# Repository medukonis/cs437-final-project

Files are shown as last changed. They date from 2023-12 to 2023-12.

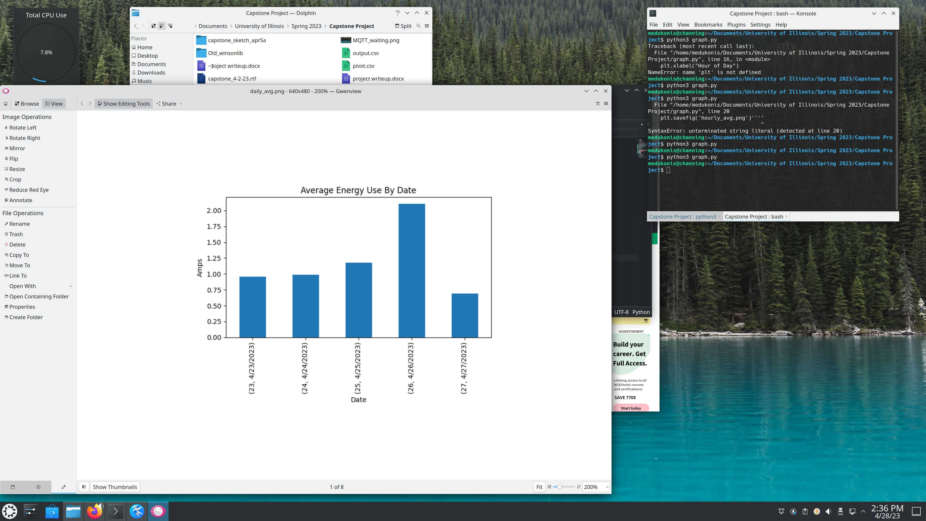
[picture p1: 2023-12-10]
Use by Date.png

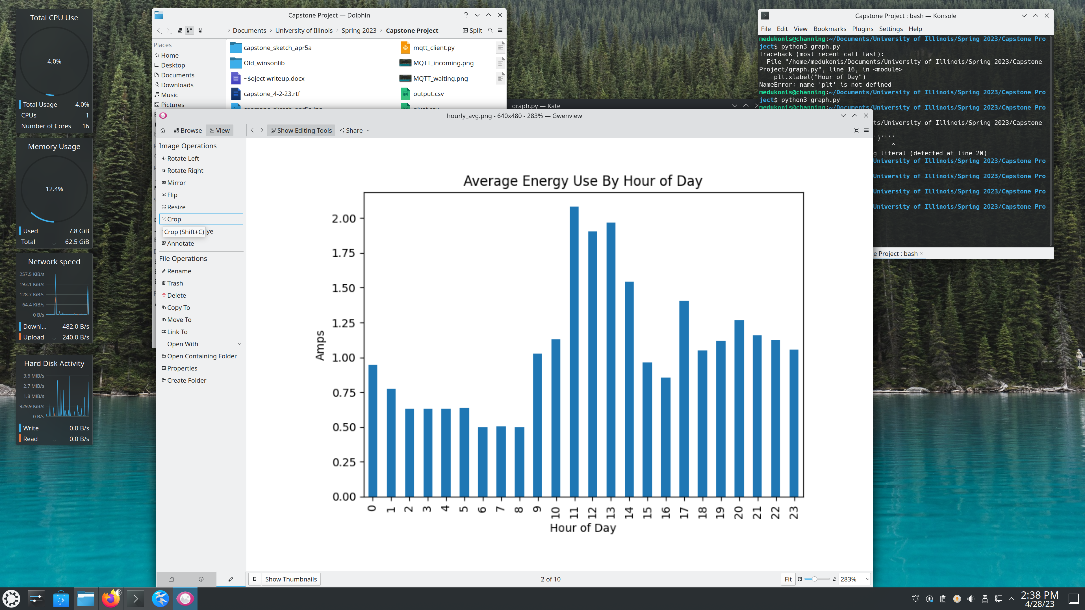
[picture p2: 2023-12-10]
Use by hour.png

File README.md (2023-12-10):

# cs437-final-project
CS437 Internet of Things
University of Illinois Urbana-Champaign
Sp2023
IoT Electricity Use Monitor - Final Project

Description
The goal of this project is to build an easy to use IoT device that will track electricity usage.  

Installation

Usage

Features

File Structure

Limitations and Known Issues

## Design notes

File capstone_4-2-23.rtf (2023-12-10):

#include <WinsonLib.h> //Hall effect sensor

#include <WiFiManager.h> //https://github.com/tzapu/WiFiManager

#include <Wire.h>

#include <Adafruit_GFX.h>

#include <Adafruit_SSD1306.h>

#include "heltec.h"

#include <time.h>

void setup()
{
Serial.begin(9600); //Hardware serial for debug messaging.
//WiFiManager
//Local intialization. Once its business is done, there is no need to keep it around
WiFiManager wifiManager;
//reset saved settings
wifiManager.resetSettings();

//set custom ip for portal
wifiManager.setAPStaticIPConfig(IPAddress(10,0,1,1), IPAddress(10,0,1,1), IPAddress(255,255,255,0));

//fetches ssid and pass from eeprom and tries to connect
//if it does not connect it starts an access point with the specified name
//here "AutoConnectAP"
//and goes into a blocking loop awaiting configuration
wifiManager.autoConnect("CS437_Proj_AP");
//or use this for auto generated name ESP + ChipID
//wifiManager.autoConnect();
//if you get here you have connected to the WiFi
Serial.println("connected... :)");
}

void loop
{

}

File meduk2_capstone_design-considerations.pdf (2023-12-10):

CS437: Internet of Things
Spring 2023 Capstone Project

Name: Michael Edukonis
NETID: meduk2
Late Days Used: 0
Video Link: https://youtu.be/vVUvGYvW_wY
Gitlab repository: https://gitlab.engr.illinois.edu/meduk2/capstone Team Members: N/A

Final Project Proposal: IoT Electricity Use Monitor

Motivation:
The goal of this project is to build an IoT device that will track electricity usage. The motivation for this build is our growing need for energy and our lack of immediate visibility of our daily energy use. This project will focus on electricity. We have the ability to utilize off the shelf parts and some ingenuity to monitor and temper our electricity use. Most households take note of their electricity use when it’s time to pay the bill. The device that may offer a glimpse into your real time electricity use, the electric meter, is inconveniently placed on the outside of the home in most situations. Smart meters are being rolled out however their abilities are lacking, and the energy companies are not motivated to spend time and resources to provide more functionality to the end user. The meter’s primary purpose is to report usage to the company for billing.

There are some products on the market that provide readings for instantaneous energy use however they do not store any usage data or provide any meaningful insights. Since a household’s main energy use is interior environment (highest) and hot water heating (2nd highest), the original thought was to track a heat pump and/or hot water heater usage with this device. It would involve a direct connection with parts that can handle the higher amperage.

Instead, this project will be a proof of concept that will focus on ease of use for the end user while utilizing standard off the shelf parts to handle 15-20 amps at 120v. The design of this device, in theory, can be expanded to anything in the household using electricity. One of the goals of this build is ease of use so the device will incorporate pass through ability, meaning the device will have male plug on one end to be plugged in to the socket and female on the other end of the device for the load to plug in to.

This device will give granular, instantaneous, and average use (through reporting) details to provide the user a very clear picture of their energy use. This information will be used to gain clarity and make informed decisions on energy use. If this device were deployed to multiple areas throughout a home or business, the data provided could be used to model costs, make the user aware of high energy use devices, and allow the user to adjust their usage of energy.

Technical approach and details:
Power monitor utilizes a WCS1800 Hall Effect Current sensor with analog output to an ESP-32 board with Wi-Fi and Bluetooth capability. The WCS1800 is pre-mounted to a board that includes the necessary circuitry for safe operation as outlined on the data sheet. The amperage being used by the circuit will be measured, stored, and broadcast on the network that it is connected to utilizing the Message Queuing Telemetry and Transport protocol (MQTT).

A hall effect current sensor provides a proportional signal in response to the strength of the magnetic field coming off the circuit being measured. The magnetic field is proportional to the amperage being pulled in the circuit. The measurement is taken from the hot part of the circuit that passes through the center of the toroid. The output of the sensor is a much smaller dc voltage that ranges in proportion to the amperage being utilized in the circuit. Because of the toroid shape, it may be challenging to simply insert the device into the circuit. Design of this device will prevent having to open the circuit to get a measurement.

The power monitor will have the ability to power itself from main power utilzing an 120v – 5v inverter and provide visual output via an OLED screen. A library is provided by the WCS1800 sensor manufacturer to conduct the calculations necessary. Output will be calibrated using known loads and another meter.

On first power up, the device will go into wireless access point mode. The user can connect to the device with their computer or phone and select their wireless access point, password, and mqtt broker details. This will be saved by the device, reboot itself and then connect to the directed access point. Device will have the ability to beacon periodic information in JSON or CSV format. Separate software (app, client, etc) can be utilized to receive this beacon and store/display the info. The board should also act as a server and provide information on demand as a client connects to it.

The device will have a safety measure built in to protect the user from excess current draw. The sensor is capable of handling 35 amps however the wiring is rated for a standard 15 amp household circuit. A 15 amp circuit breaker is connected at the point electricity enters the device.

Software:
ESP 32 board is programmable using the Arduino environment.
- Microsoft Visual Studio Code was also utilized for coding the project.
- Arduino provided MQTT client for publishing was utilized
- Wifi Manager provided by https://github.com/tzapu
- Do not have to hardcode wifi AP or MQTT credentials
- Adafruit provided library for OLED screen on the ESP32 board.
- MQTT payload is in CSV format consisting of:
- Date, Time (UTC), mqtt topic, Amps reading.

- Setup includes time sync with ntp.org. Once setup is completed, the reading takes place in the loop function at 1 second intervals.

Mosquitto MQTT Broker was installed on a linux desktop
- Custom MQTT client coded in python utilizing paho mqtt library

WCS_1800 sensor
A software library is provided by the company that makes the WCS_1800 sensor (Winson Semiconductor). The library is not compatible as is with ESP32 but some minor adjustments make it usable. These adjustments are explained under results and challenges.

Python scripts utilizing mapplotlib and pandas provide visual analysis of historic usage metrics for daily and hourly basis. Ideally, these will be run on a cron schedule and visuals will be saved to png or jpeg file and copied to the Apache2 webserver directory on the linux desktop.

Project Timeline for deliverables:
Milestone | Due Date | Status
Submit Proposal | 20-Feb-23 | Completed
Obtain parts | 25-Feb-23 | Completed
Test individual parts/order replacements | 4-Mar-23 | Completed
Wire prototype | 11-Mar-23 | Completed
Measure/order enclosure | 18-Mar-23 | Completed
Write software | 19-Mar-23 | Completed
Test/Debug/refactor | 25-Mar-23 | Completed
Modify/set/mount to enclosure | 1-Apr-23 | Completed
Expand notes/findings into report | 28-Apr-23* | Completed
Produce Video | 29-Apr-23* | Completed
Submit Report and Video | 29-Apr-23* | Completed
*adjusted

Results and Challenges
The project is a success. Most of the original project proposal ideas were implemented without change however there were some challenges that needed to be resolved along the way:
- ESP32 OLED screen cable was too short to mount board inside with screen outside box. Next version will utilize a separate oled screen to give more mounting options. This issue was overcome with a design change to the enclosure.
- ESP32 OLED screen was too small to show all information at once
- Software adjustment changes the screen output at 10 second intervals.

- The enclosure was printed multiple times in an attempt to shrink it as much as possible. Success was achieved with 100mm x 50mm box however assembly was very tight.
- Different/smaller circuit breaker or resettable fuse would be helpful.
- Layout parts and assemble on a custom PCB would aid assembly.

WCS_1800 sensor requires sensitivity adjustment in the software to dial in results. The procedure involved an inline and clamp ammeters on the live circuit to compare results and adjust accordingly (photo below).

Winson provides an Arduino library to aid in the development and use of their products however it is one library to be used with multiple devices that they manufacture. The library is written specifically for atmel AVR chip used on most Arduino boards. The library was not compatible with the Espressif ESP32 utilized in this project. Specifically, the SoftwareSerial implementation required by another Winson sensor was preventing the compiling of the library with this project. To overcome this problem, the code in wcs.h and wcs.cpp library files was refactored to eliminate everything except the class required for WCS_1800 sensor.

Board continues working but stops transmitting over the network after approximately 8 hours. This requires a reset of the board which simply involves a button push. Network and MQTT credentials are stored so it reconnects automatically upon reboot however the reason for the bug is not yet understood. Further debugging is required and possibly implement a watchdog timer to reboot the device.

The power cord requires some kind of strain relief.

Physical Characteristics and circuit design
*Hall effect sensor used in place of a current transformer.

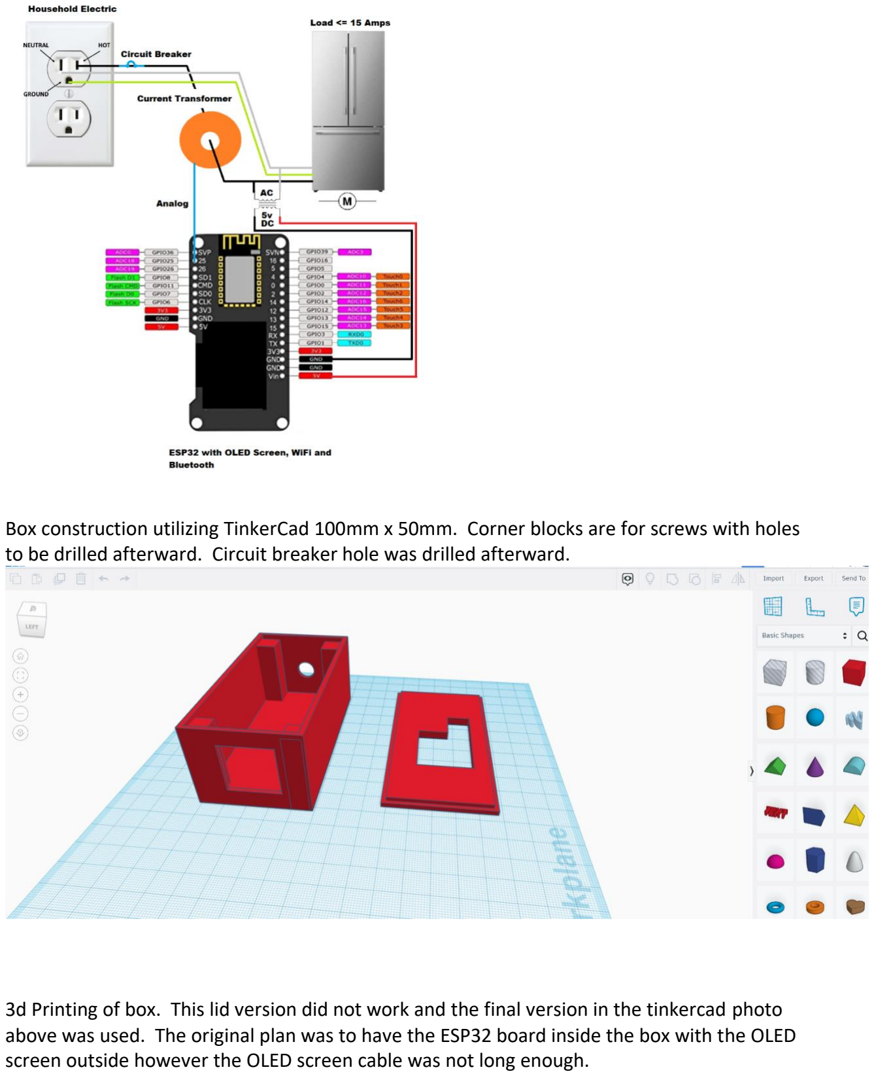
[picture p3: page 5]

Box construction utilizing TinkerCad 100mm x 50mm. Corner blocks are for screws with holes to be drilled afterward. Circuit breaker hole was drilled afterward.

3d Printing of box. This lid version did not work and the final version in the tinkercad photo above was used. The original plan was to have the ESP32 board inside the box with the OLED screen outside however the OLED screen cable was not long enough.

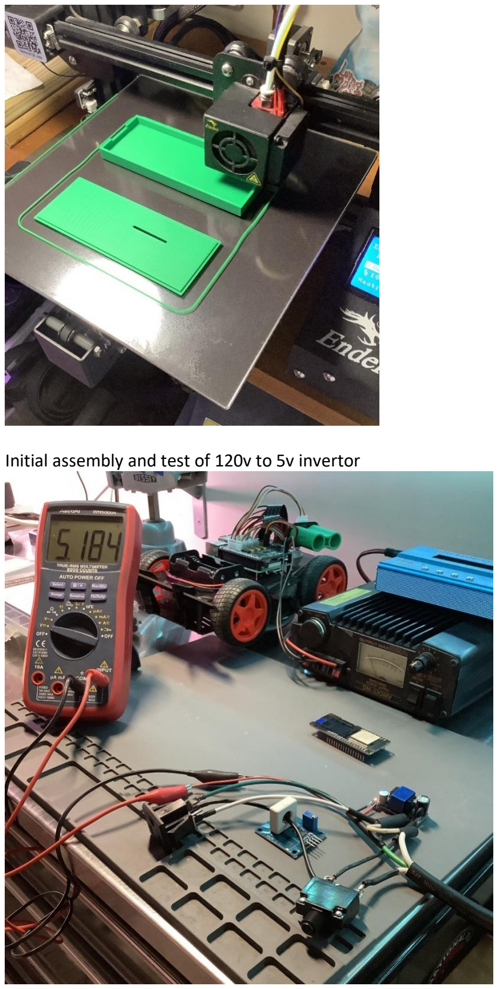
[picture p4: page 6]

Initial assembly and test of 120v to 5v invertor

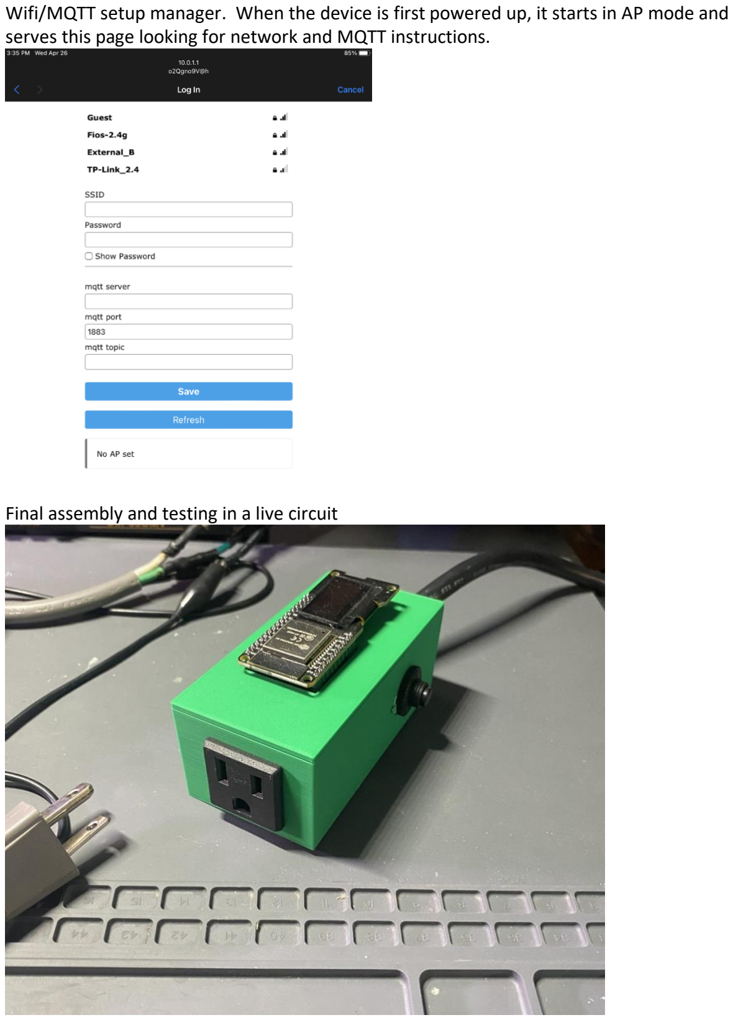
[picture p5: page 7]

Wifi/MQTT setup manager. When the device is first powered up, it starts in AP mode and serves this page looking for network and MQTT instructions.

Final assembly and testing in a live circuit

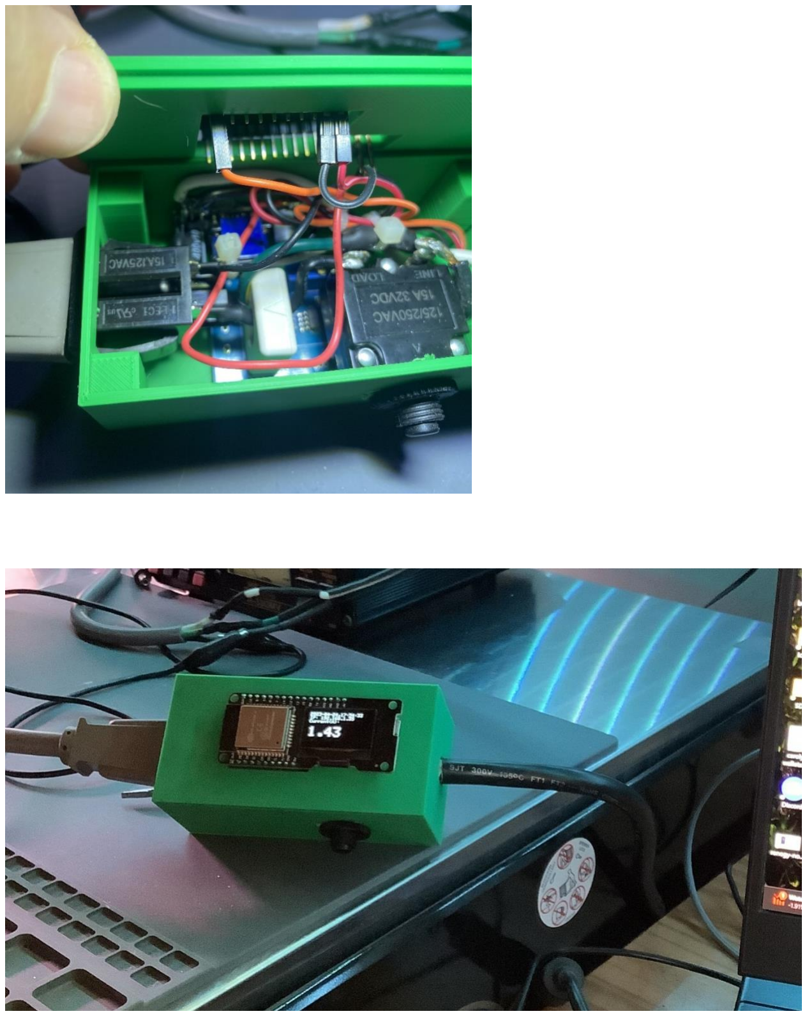
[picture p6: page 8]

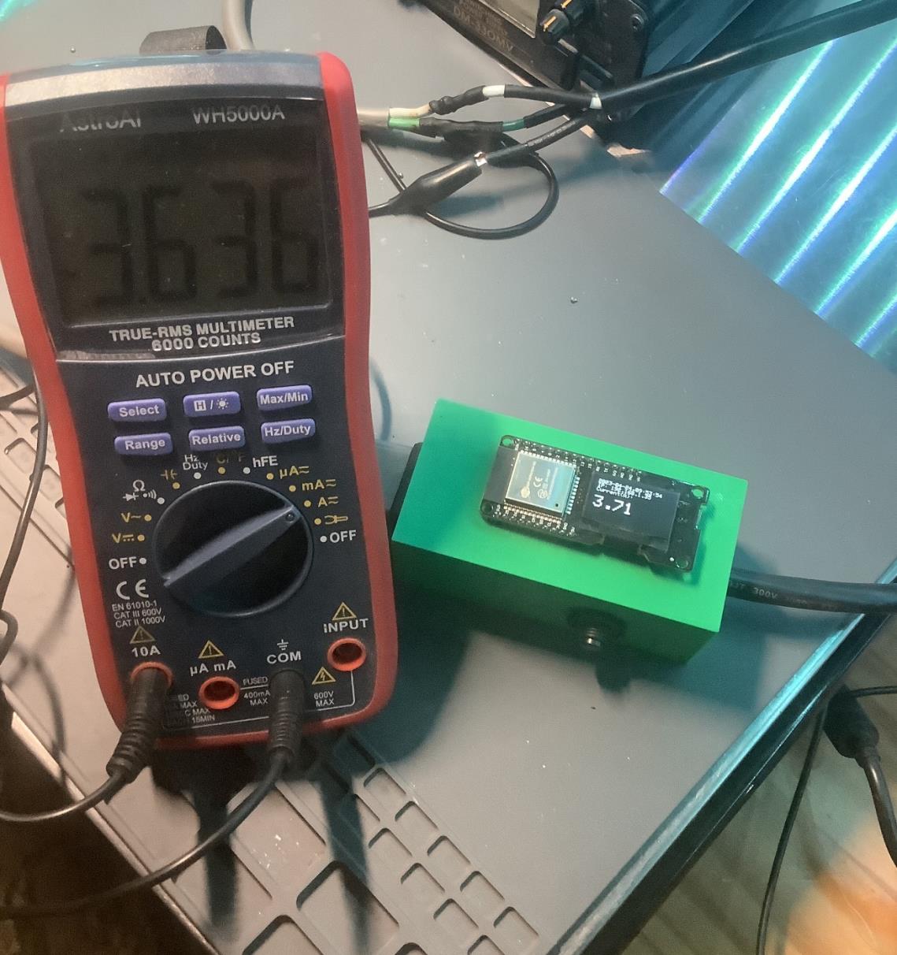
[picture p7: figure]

Testing and adjustment with inline and clamp ammeters.

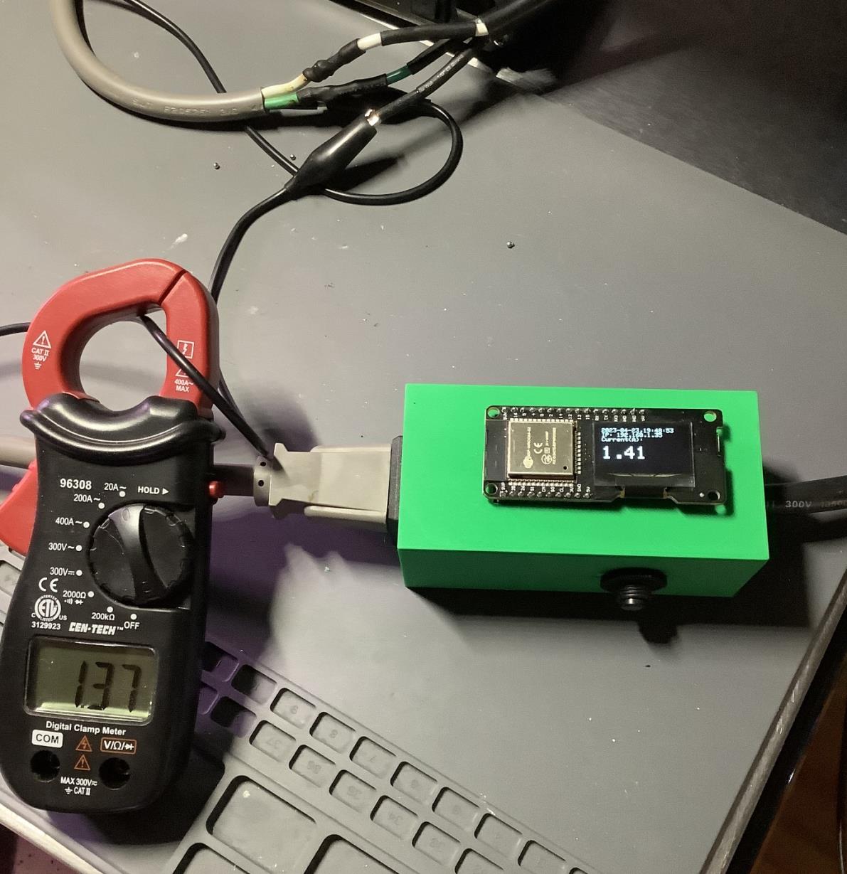
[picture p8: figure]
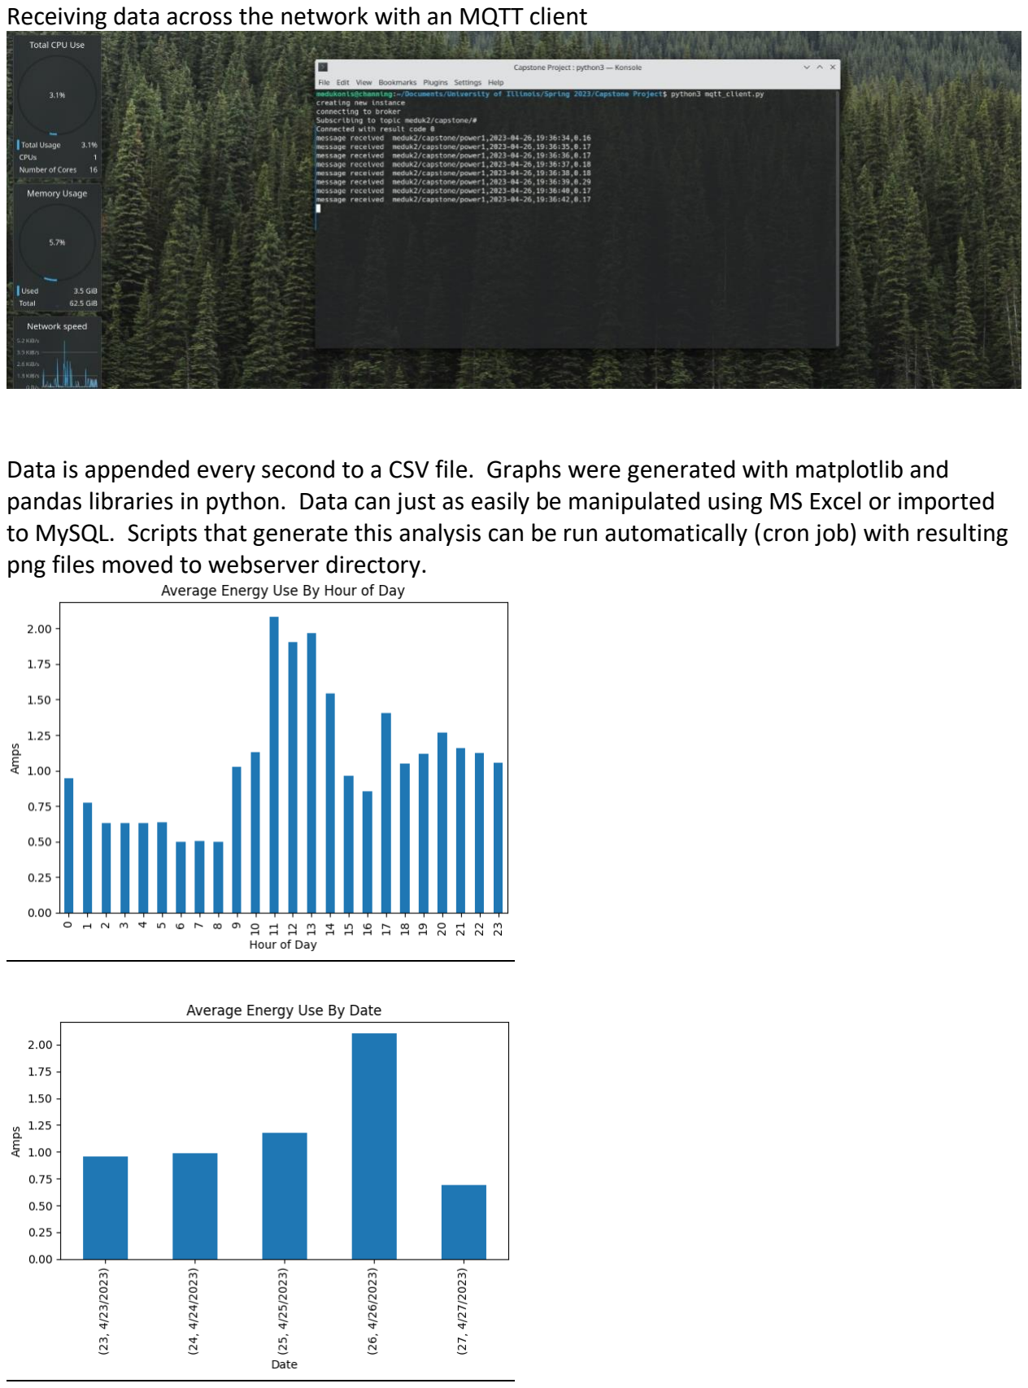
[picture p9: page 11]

Receiving data across the network with an MQTT client

Data is appended every second to a CSV file. Graphs were generated with matplotlib and pandas libraries in python. Data can just as easily be manipulated using MS Excel or imported to MySQL. Scripts that generate this analysis can be run automatically (cron job) with resulting png files moved to webserver directory.

Build Parts:
Board - https://www.amazon.com/HiLetgo-ESP-WROOM-32-Bluetooth-Development-Display/dp/B072HBW53G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 (https://www.amazon.com/HiLetgo-ESP-WROOM-32-Bluetooth-Development-Display/dp/B072HBW53G)

Female plug end bulkhead
https://www.amazon.com/gp/product/B092VQNKN7/ref=ppx_yo_dt_b_asin_title_o03_s00?ie=UTF8&th=1 (https://www.amazon.com/gp/product/B092VQNKN7/ref=ppx_yo_dt_b_asin_title_o03_s00?ie=UTF8&th=1)

WCS1800 Hall Effect Current Sensor https://www.amazon.com/Comimark-WCS1800-Current-Detection-Overcurrent/dp/B07XY7NT6K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 (https://www.amazon.com/Comimark-WCS1800-Current-Detection-Overcurrent/dp/B07XY7NT6K)

Inverter – 120v AC to 5v DC 2 amp https://www.amazon.com/Converter-Universal-Isolated-Switching-Version/dp/B07SGQ6XXR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 (https://www.amazon.com/Converter-Universal-Isolated-Switching-Version/dp/B07SGQ6XXR)

15A Circuit Breaker
https://www.amazon.com/gp/product/B088R8DKLP/ref=ppx_yo_dt_b_search_asin_title?ie=UTF8&th=1 (https://www.amazon.com/gp/product/B088R8DKLP/ref=ppx_yo_dt_b_search_asin_title?ie=UTF8&th=1)

Works Cited

Storr, Wayne. “Hall Effect Sensor and How Magnets Make It Works.” Basic Electronics Tutorials, 6 Aug. 2022, https://www.electronics-tutorials.ws/electromagnetism/hall-effect.html.

Hall Effect Base Linear Current Sensor - Winson. 29 Sep. 2020https://www.winson.com.tw/uploads/images/WCS1800.pdf.

WinsonLib Application Notes. Winson Semiconductor Corp, 21 July 2022, https://www.winson.com.tw/uploads/images/WinsonLib_ApplicationNote.pdf.

Tzapu. “TZAPU/WiFiManager: Esp8266 WIFI Connection Manager with Web Captive Portal.” GitHub, Dec. 2022, https://github.com/tzapu/WiFiManager.

Craggs, Ian. “Eclipse Paho: The Eclipse Foundation.” The Community for Open Innovation and Collaboration, (Python MQTT library) https://www.eclipse.org/paho/.

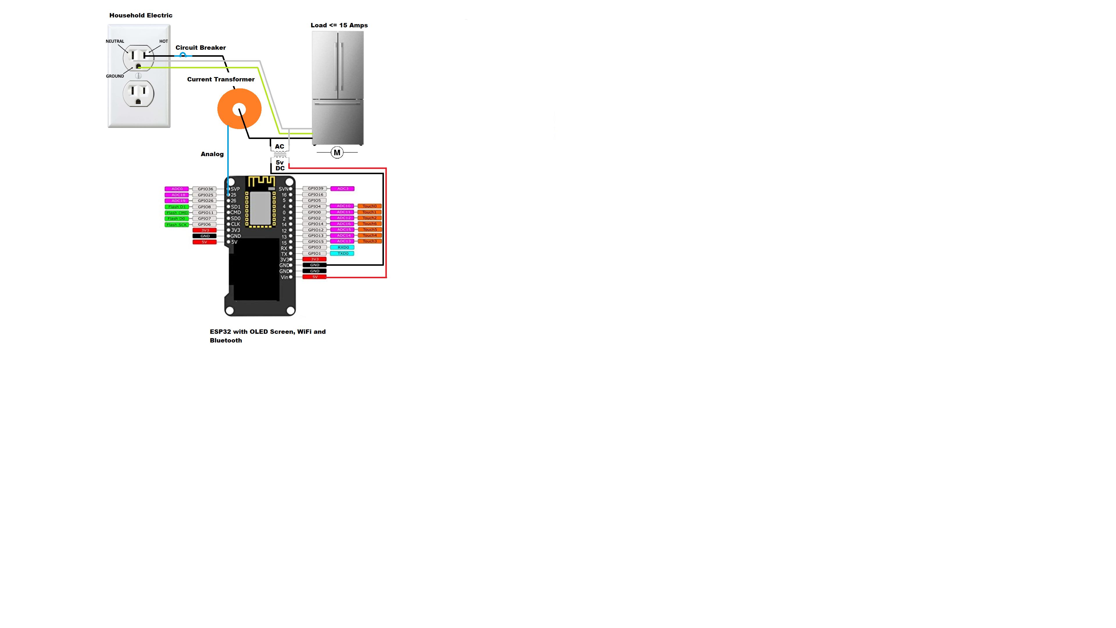
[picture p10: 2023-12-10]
layout.png

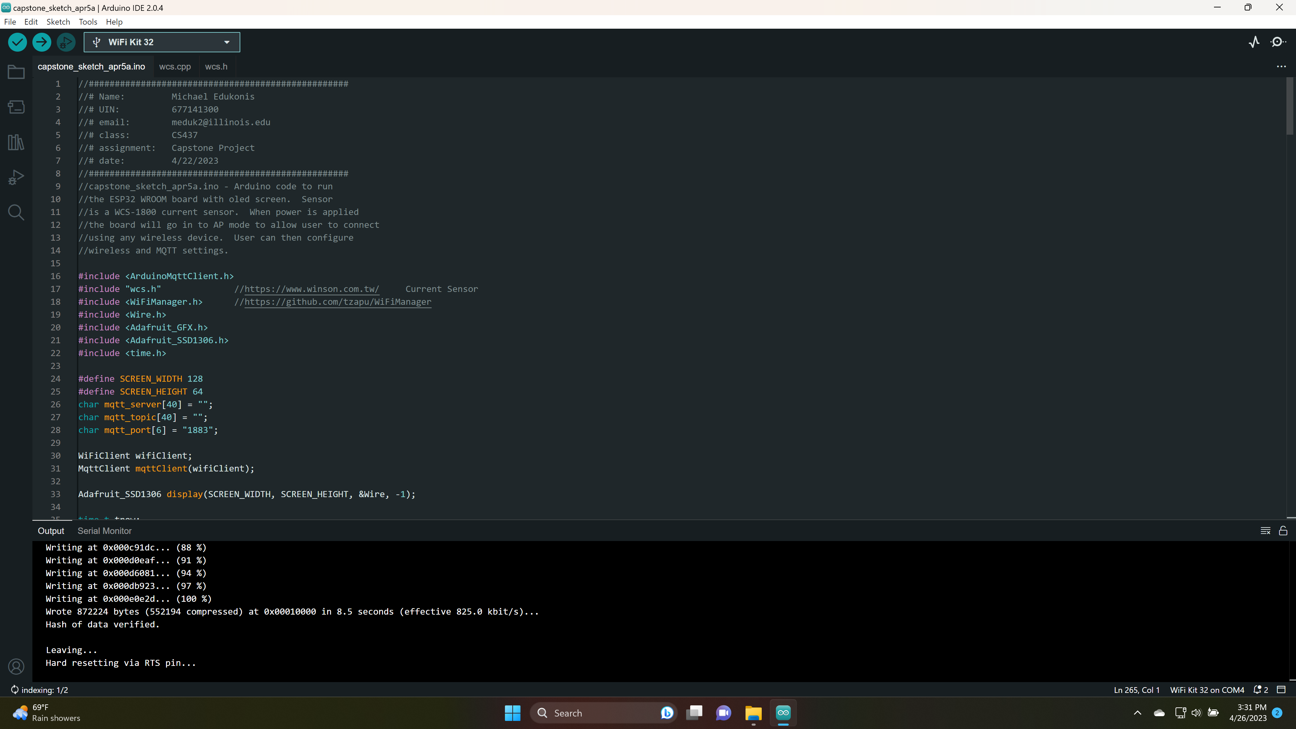
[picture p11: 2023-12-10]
upload.png

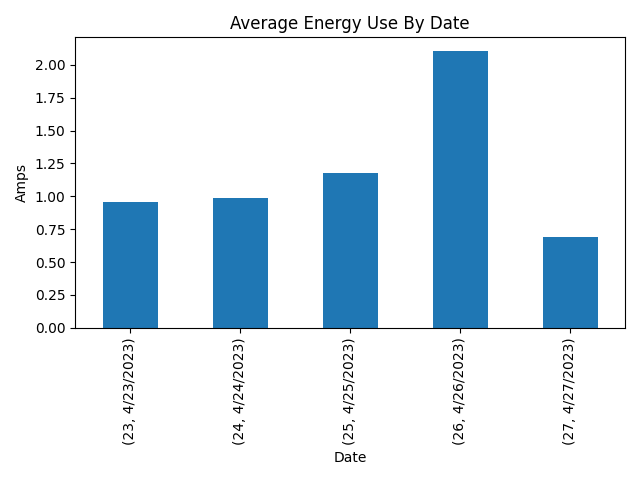
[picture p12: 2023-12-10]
daily_avg.png

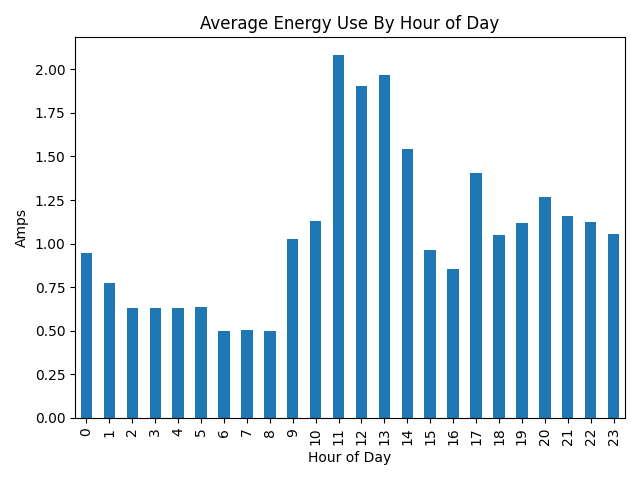
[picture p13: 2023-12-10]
hourly_avg.png

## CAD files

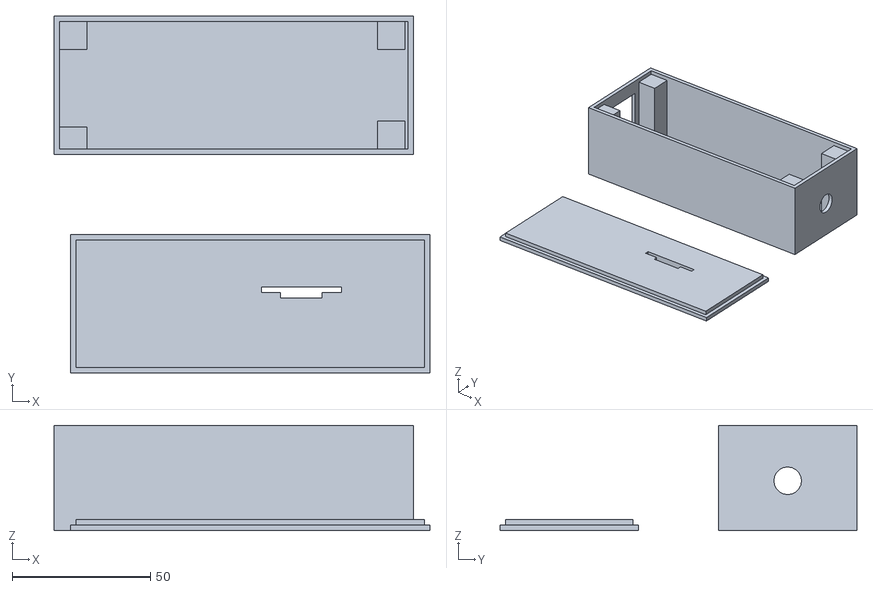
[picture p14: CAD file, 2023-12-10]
MEDUK2 - CS437 Capstone Project Spring 2023v3.stl
136.0 x 129.0 x 38.0

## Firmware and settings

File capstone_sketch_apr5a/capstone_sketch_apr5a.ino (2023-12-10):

//##################################################
//# Name:         Michael Edukonis
//# UIN:          677141300
//# email:        meduk2@illinois.edu
//# class:        CS437
//# assignment:   Capstone Project
//# date:         4/22/2023
//##################################################
//capstone_sketch_apr5a.ino - Arduino code to run
//the ESP32 WROOM board with oled screen.  Sensor
//is a WCS-1800 current sensor.  When power is applied
//the board will go in to AP mode to allow user to connect
//using any wireless device.  User can then configure
//wireless and MQTT settings.

#include <ArduinoMqttClient.h>
#include "wcs.h"              //https://www.winson.com.tw/     Current Sensor
#include <WiFiManager.h>      //https://github.com/tzapu/WiFiManager
#include <Wire.h>
#include <Adafruit_GFX.h>
#include <Adafruit_SSD1306.h>
#include <time.h>

#define SCREEN_WIDTH 128
#define SCREEN_HEIGHT 64
char mqtt_server[40] = "";
char mqtt_topic[40] = "";
char mqtt_port[6] = "1883";

WiFiClient wifiClient;
MqttClient mqttClient(wifiClient);

Adafruit_SSD1306 display(SCREEN_WIDTH, SCREEN_HEIGHT, &Wire, -1);

time_t tnow;
char dateTime[20];
static char ap_name[10];
double data = 0;
// Setting Analog Pin & Sensitivity(mV/A)
WCS  WCS1 = WCS( 36, _WCS1800);
int loopCount = 0;


void setup() 
{
  Serial.begin(115200);
  
  // Start I2C Communication SDA = 5 and SCL = 4 on ESP32 with built-in SSD1306 OLED
  Wire.begin(5, 4);  

  if(!display.begin(SSD1306_SWITCHCAPVCC, 0x3C, false, false)) {
    Serial.println(F("SSD1306 allocation failed"));
    for(;;);
  }
  delay(2000); // Pause for 2 seconds
  
  // WCS1800 sensor - Power-on Reset
  Serial.println("Reset");
  WCS1.Reset(); 

 //display.begin(SSD1306_SWITCHCAPVCC, OLED_ADDR);
  display.clearDisplay();
  display.setTextSize(2);
  display.setTextColor(WHITE);
  display.setCursor(0, 0);
  display.println("Welcome");

  display.setTextSize(1);
  display.setTextColor(WHITE);
  display.setCursor(0, 17);

  //Setup Wireless
  //Open up AP mode to allow users to connect via wireless
  //Get random string of length 10 and this will be the access point name for WiFi setup
  //Show the AP name on the oled screen
  get_random_string(ap_name, 10);
  display.println("Waiting to");
  display.println("connect to WIFI");
  display.print("AP: ");
  display.println(ap_name);
  display.display();

  //Setup some additional needed parameters for this implementation
  //3 settings needed for MQTT
  WiFiManagerParameter custom_mqtt_server("server", "mqtt server", mqtt_server, 40);
  WiFiManagerParameter custom_mqtt_port("port", "mqtt port", mqtt_port, 6);
  WiFiManagerParameter custom_mqtt_topic("topic", "mqtt topic", mqtt_topic, 40);

  //Setup instance of wifi manager.  
  WiFiManager wifiManager;
  
  //reset saved settings
  //Normally, this would be commented out however for demonstration purposes,
  //wifi settings will not be saved when power is lost.
  wifiManager.resetSettings();
   
  //set custom ip for portal 10.0.1.1
  wifiManager.setAPStaticIPConfig(IPAddress(10,0,1,1), IPAddress(10,0,1,1), IPAddress(255,255,255,0));
  
  //add MQTT parameters here
  wifiManager.addParameter(&custom_mqtt_server);
  wifiManager.addParameter(&custom_mqtt_port);
  wifiManager.addParameter(&custom_mqtt_topic);
  
  //fetches ssid and pass from eeprom and tries to connect
  //if it does not connect it starts an access point with the
  //name sent back by the random string generator
  //and goes into a blocking loop awaiting configuration
  wifiManager.autoConnect(ap_name);
  
  //or use this for auto generated name ESP + ChipID
  //wifiManager.autoConnect();
  
  //if you get here you have connected to the WiFi
  Serial.println("connected...");
  
  //read updated MQTT parameters
  strcpy(mqtt_server, custom_mqtt_server.getValue());
  strcpy(mqtt_port, custom_mqtt_port.getValue());
  strcpy(mqtt_topic, custom_mqtt_topic.getValue());
  Serial.println("The values in the file are: ");
  Serial.println("\tmqtt_server : " + String(mqtt_server));
  Serial.println("\tmqtt_port : " + String(mqtt_port));
  Serial.println("\tmqtt_topic : " + String(mqtt_topic));
  
  Serial.println(WiFi.localIP());
  display.clearDisplay();
  display.setTextSize(2);
  display.setTextColor(WHITE);
  display.setCursor(0, 17);
  display.print("IP Address: ");
  display.print(WiFi.localIP().toString());

  if (!mqttClient.connect(mqtt_server, atoi(mqtt_port))) 
  {
    Serial.print("MQTT connection failed! Error code = ");
    display.println("MQTT connection failed! Error code = ");
    display.println(mqttClient.connectError());
    Serial.println(mqttClient.connectError());
    while (1);
  }
  
  
//Setup Timekeeping
//#########################################################################################################################
  configTime(0, 0, "0.north-america.pool.ntp.org", "1.north-america.pool.ntp.org", "2.north-america.pool.ntp.org");
  Serial.println("\nWaiting for time");
  while (time(nullptr)<= 100000)
  {
    Serial.print(".");
    delay(100);
  }
    
  Serial.println("");
  tnow = time(nullptr);
  tm *ptm = localtime(&tnow);
  strftime(dateTime, 20, "%Y-%m-%d,%H:%M:%S,", ptm);
  Serial.println(dateTime);
//#########################################################################################################################
  
  delay(5000);
}

void loop() 
{
  //######################################
  // Update Time
  //######################################
  tnow = time(nullptr);
  tm *ptm = localtime(&tnow);
  strftime(dateTime, 20, "%Y-%m-%d,%H:%M:%S", ptm);
  //Serial.println(dateTime);
  
  //######################################
  // Measure AC Current
  //######################################
  data = WCS1.A_AC();
  
  Serial.print("Current(A) : ");
  Serial.println(String(data,3) + " A" +  "\t MQTT Topic: " + String(mqtt_topic) + "\t Server: " + String(mqtt_server) + "\t Port: " + String(mqtt_port));
  
  
  //######################################
  // Display information on OLED screen
  // loop has a 1 second delay so we use
  // that to keep count.  Everyone 10 
  // seconds, the OLED screen will alternate
  // it's information being displayed
  // because it could not all fit on one
  //######################################
  if (loopCount >= 10 && loopCount <= 20)
  {
    display.clearDisplay();
    display.setTextSize(1);
    display.setTextColor(WHITE);
    display.setCursor(0, 0);
    display.println("Server:"); 
    display.println(String(mqtt_server));
    display.println("Port: " + String(mqtt_port));
    display.println("Topic:");
    display.println(String(mqtt_topic));
    display.setTextSize(2);
    display.print(data);
    display.println("  A");
    display.display();
    if (loopCount == 20)
    {
      loopCount = 0;
    }
  }
 
  else
  {
    display.clearDisplay();
    display.setTextSize(1);
    display.setTextColor(WHITE);
    display.setCursor(0, 0);
    display.println(dateTime);
    display.print("IP: ");
    display.println(WiFi.localIP().toString()); 
    display.println("Current(A):\n");
    display.setTextSize(3);
    display.print(data);
    display.println("  A");
    display.display();
  }

  //######################################
  // Send Data to MQTT Broker
  //######################################
  mqttClient.beginMessage(mqtt_topic);
  mqttClient.print(String(mqtt_topic) + "," + String(dateTime) + "," + String(data));
  mqttClient.endMessage();

  loopCount += 1;
  delay(1000);
  
}

//#######################################################
//Function: get_random_string
//Input: char *, unsigned int
//Output: None
//Generates random string in "str" of length "len" chars
//writes directly to the passed variable using a pointer
//#######################################################

static void get_random_string(char *str, unsigned int len)
{
    unsigned int i;
    const char possible_values[] = "ABCDEFGHIJKLMNOPQRSTUVWXYZabcdefghijklmnopqrstuvwxyz0123456789$&*!@";

    // reseed the random number generator
    srand(time(NULL));
    
    for (i = 0; i < len; i++)
    {
        // Add random printable ASCII char
        int r = random(0, strlen(possible_values));
        str[i] = possible_values[r];
    }
    str[i] = '\0';
}
